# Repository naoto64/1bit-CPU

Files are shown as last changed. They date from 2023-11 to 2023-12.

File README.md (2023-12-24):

# 1bit-CPU
1bit CPU using 74HC series logic IC.

## Overview
This is a 1bit CPU KiCad file.
You can make a CPU using the 74HC series logic IC.

## Circuit Diagram
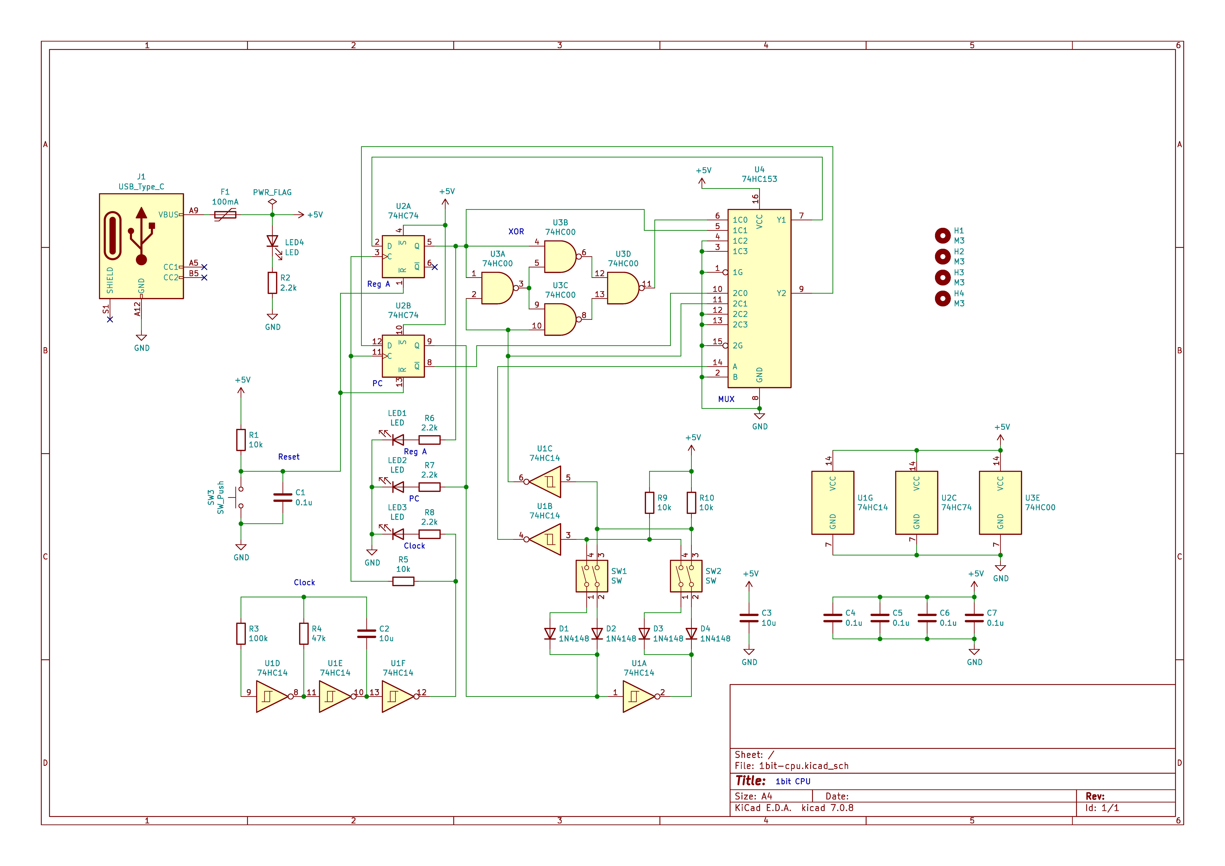
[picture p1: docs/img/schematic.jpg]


## Description
Left switch: Controls MUX to choose whether to update Reg A or PC  
Right switch: Controls second XOR operand or sets destination PC address

```
LR
00: MUX=0, RA=RA^0=RA,  PC=!PC
01: MUX=0, RA=RA^1=!RA, PC=!PC
10: MUX=1, RA=RA,       PC=0
11: MUX=1, RA=RA,       PC=1
```

In regular words:  
OFF, OFF will preserve the value of A and advance PC (0->1, 1->0)  
OFF, ON will invert the value of A (0->1, 1->0) and advance PC (0->1, 1->0)  
ON, OFF will preserve the value of A and set PC to 0  
ON, ON will preserve the value of A and set PC to 1  

```
01 23 | Function | Looped C equivalent | Description
----------------------------------------------------------------------------
00 00 | NOP, NOP | void; void;         | Do nothing
00 01 | NOP, INV | void; a=!a;         | Half frequency blink
00 10 | NOP, NOP | void; void;         | Do nothing
00 11 | NOP, HLT | void; while(1);     | Halt forever
01 00 | INV, NOP | a=!a; void;         | Half frequency blink
01 01 | INV, INV | a=!a; a=!a;         | Maximum frequency blink
01 10 | INV, NOP | a=!a; void;         | Half frequency blink
01 11 | INV, HLT | a=!a; while(1);     | Usually one state change, then halt
10 00 | HLT, NOP | while(1); void;     | Halt forever
10 01 | HLT, INV | while(1); a=!a;     | At most one state change, then halt
10 10 | HLT, NOP | while(1); void;     | Halt forever
10 11 | HLT, HLT | while(1); while(1); | Halt forever
11 00 | NOP, NOP | void; void;         | Do nothing
11 01 | NOP, INV | void; a=!a;         | Half frequency blink
11 10 | NOP, NOP | void; void;         | Do nothing
11 11 | NOP, HLT | void; while(1);     | Halt forever
```

## Video
1bit-CPU (https://www.youtube.com/watch?v=7_g6IDrb5PI)

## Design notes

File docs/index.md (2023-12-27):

# 1bit CPU 組み立てキット

## 概要
4個のロジックICを使用した1bit CPUの組み立てキットです。
超低性能なコンピュータのため、Lチカ、LED点灯、LED消灯のいずれかしかできません。
世界トップクラスの低性能コンピュータです。

電源はUSB Type-C端子です。ACアダプタ、ケーブルは付属しておりませんので別途ご用意ください。また、PowerDelivery等の給電には対応しておりませんのでご注意ください。

## 購入
この製品は以下のサイトから購入できます。  
[スイッチサイエンス - 1bit CPU 組み立てキット](https://www.switch-science.com/products/9376 "1bit CPU 組み立てキット")

#### お問い合わせフォーム
[製品に関するお問い合わせ](https://forms.gle/Fn5E3byABXJ8P5sbA)

## 使用方法
ROM書き込みはDIPスイッチを切り替えることで可能です。

DIPスイッチは上側がONです。プログラムで赤色LEDの点灯動作が変わります。赤色のリセットボタンを押すとリセットできます。

## スペック
<table>
  <thead>
    <tr>
      <th>項目</th>
      <th>スペック</th>
    </tr>
  </thead>
  <tbody>
    <tr>
        <td>汎用レジスタ</td>
        <td>1bit x 1</td>
    </tr>
    <tr>
        <td>アドレス空間</td>
        <td>2bit</td>
    </tr>
    <tr>
        <td>アドレスバス幅</td>
        <td>1bit</td>
    </tr>
    <tr>
        <td>ROM容量</td>
        <td>4bit</td>
    </tr>
    <tr>
        <td>命令セット</td>
        <td>ADD, JMP</td>
    </tr>
    <tr>
        <td>プログラムカウンタ</td>
        <td>1bit</td>
    </tr>
    <tr>
        <td>フラグレジスタ</td>
        <td>未実装</td>
    </tr>
    <tr>
        <td>算術演算</td>
        <td>1bitの加算（XOR）</td>
    </tr>
    <tr>
        <td>クロック周波数</td>
        <td>約1Hz</td>
    </tr>
    <tr>
        <td>IC総数</td>
        <td>4個</td>
    </tr>
  </tbody>
</table>

## 命令セット
<table>
  <thead>
    <tr>
      <th>命令</th>
      <th>機械語</th>
      <th>説明</th>
    </tr>
  </thead>
  <tbody>
    <tr>
        <td>ADD A, Im</td>
        <td>0</td>
        <td>AレジスタにIm（イミディエイトデータ）を加算する。</td>
    </tr>
    <tr>
        <td>JMP Im</td>
        <td>1</td>
        <td>Imで指定した先の番地へジャンプする。</td>
    </tr>
  </tbody>
</table>

## プログラム例
#### Aレジスタに1を加算し続けるプログラム（Lチカ）
ニモニック
```text:
ADD A, 1
JMP 0
```

DIPスイッチ
```text:
OFF　ON　ON　OFF
```

#### Aレジスタに1を加算するだけのプログラム
ニモニック
```text:
ADD A, 1
JMP 1
```

DIPスイッチ
```text:
OFF　ON　ON　ON
```

#### 何もしないプログラム
ニモニック
```text:
JMP 0
```

DIPスイッチ
```text:
ON　OFF　ON　OFF
```

## 回路図
回路図

## 実装図
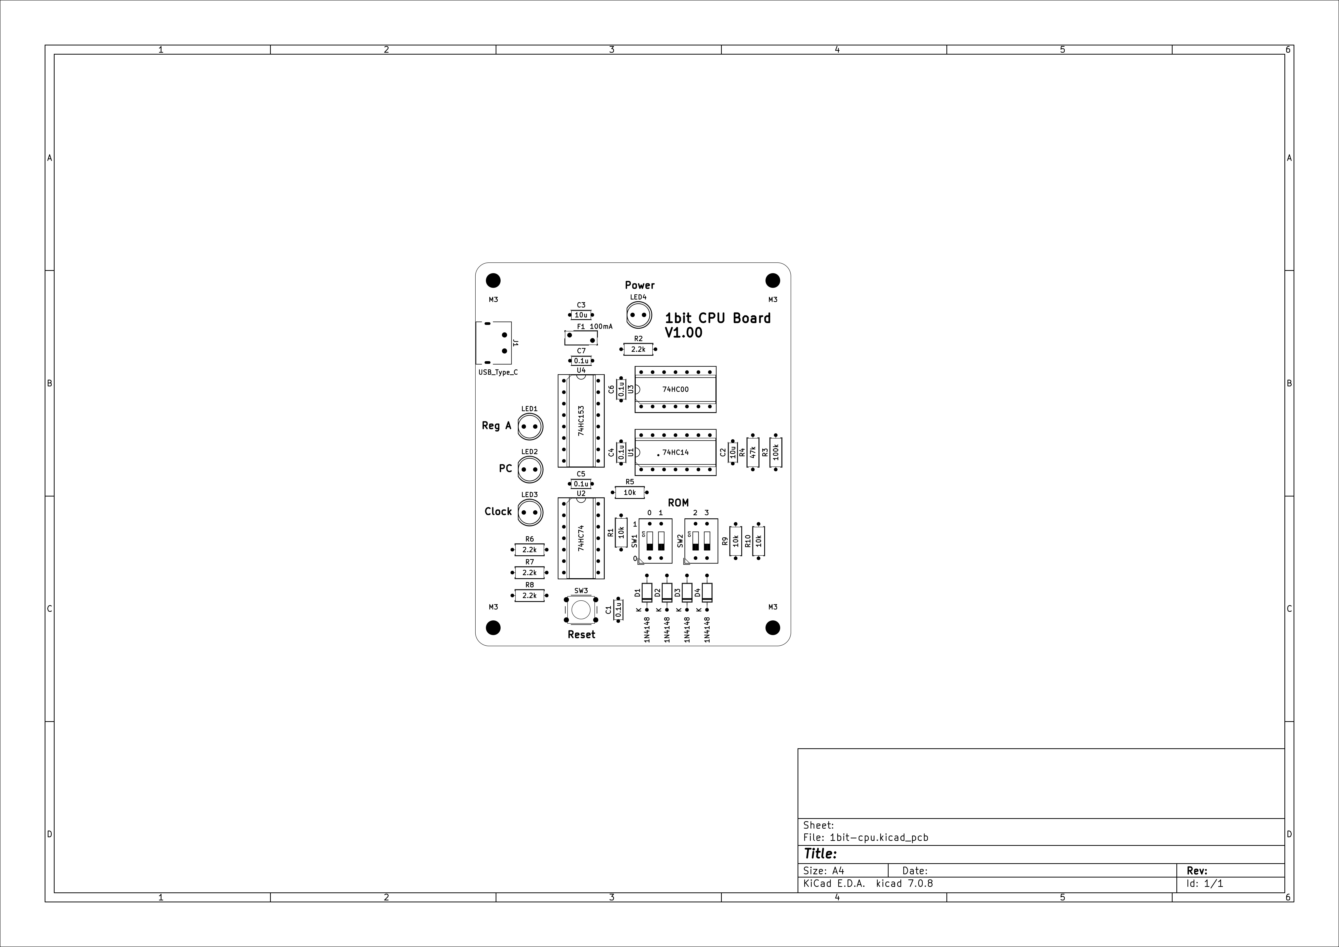
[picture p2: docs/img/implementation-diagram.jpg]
実装図


## 実装例
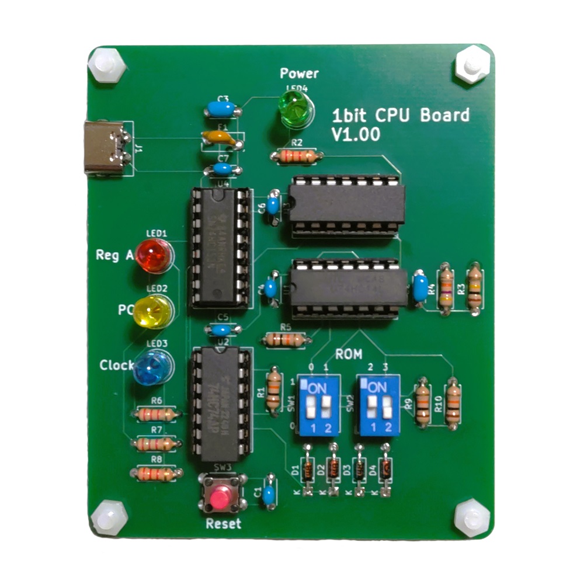
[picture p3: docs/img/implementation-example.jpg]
実装例


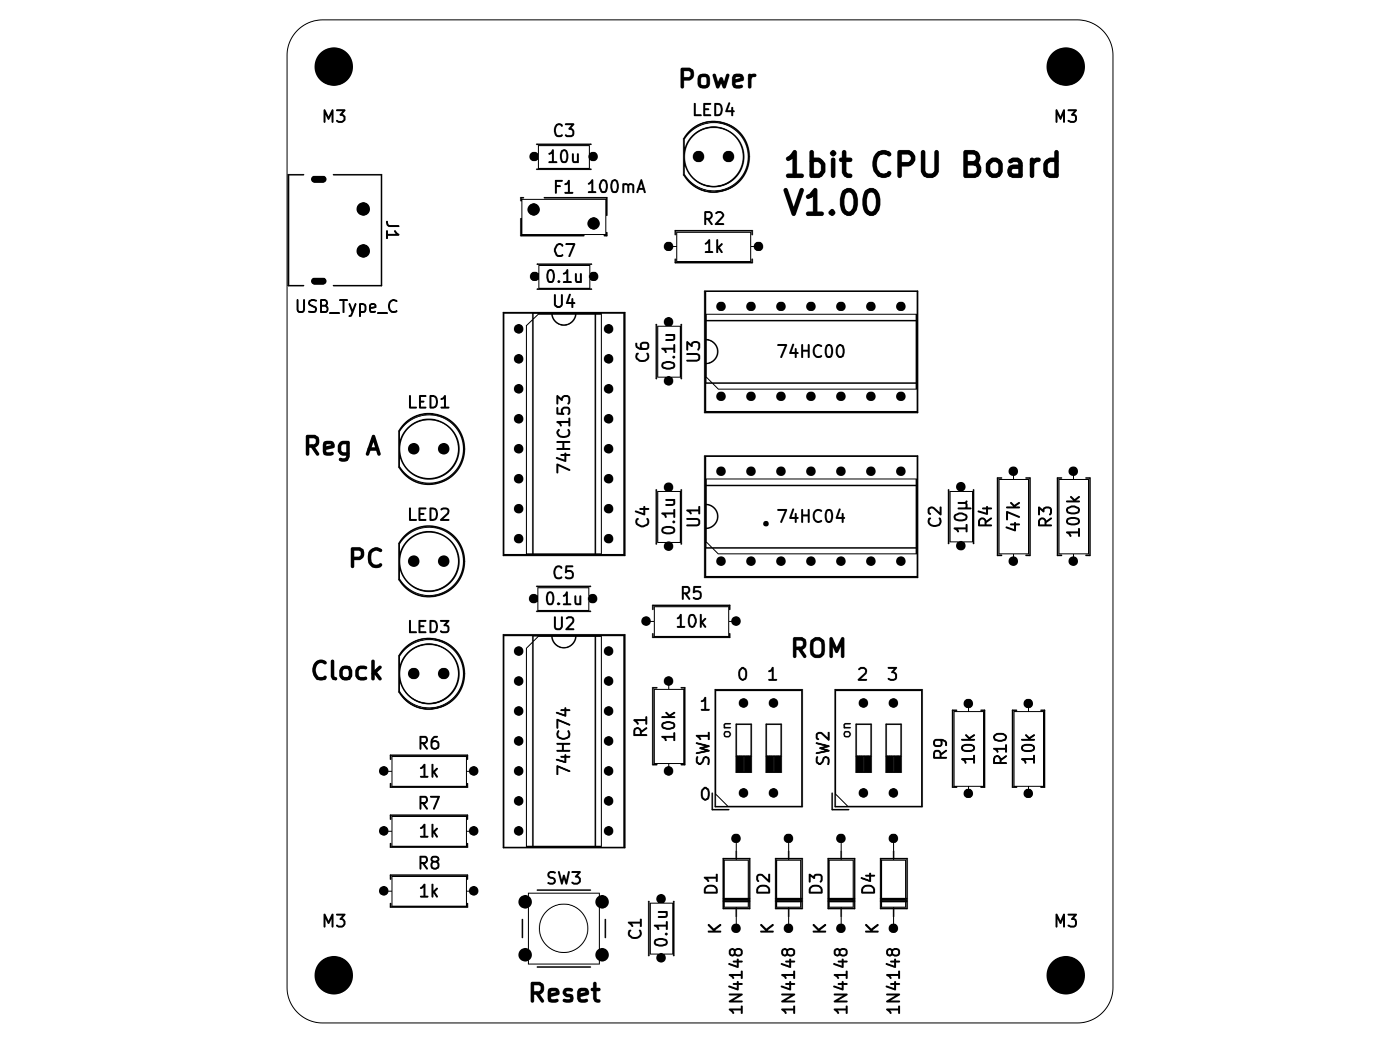
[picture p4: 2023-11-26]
1bit-cpu/実装図.png

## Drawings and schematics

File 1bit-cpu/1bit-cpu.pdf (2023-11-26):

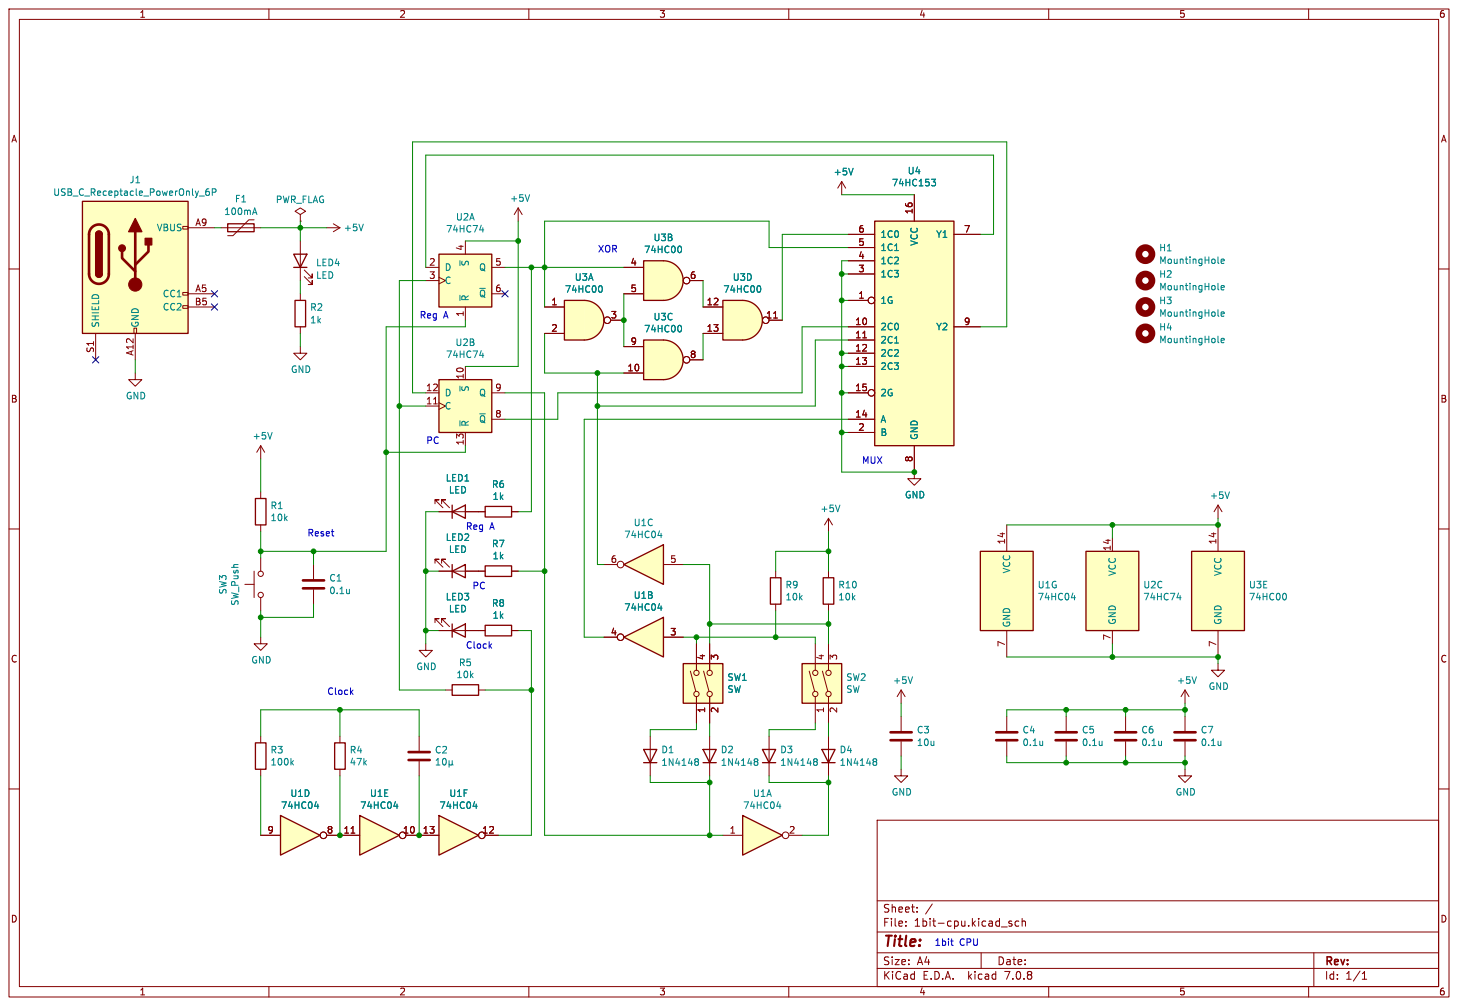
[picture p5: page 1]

74HC00 +5V H2 MountingHole H1 MountingHole H3 MountingHole H4 MountingHole

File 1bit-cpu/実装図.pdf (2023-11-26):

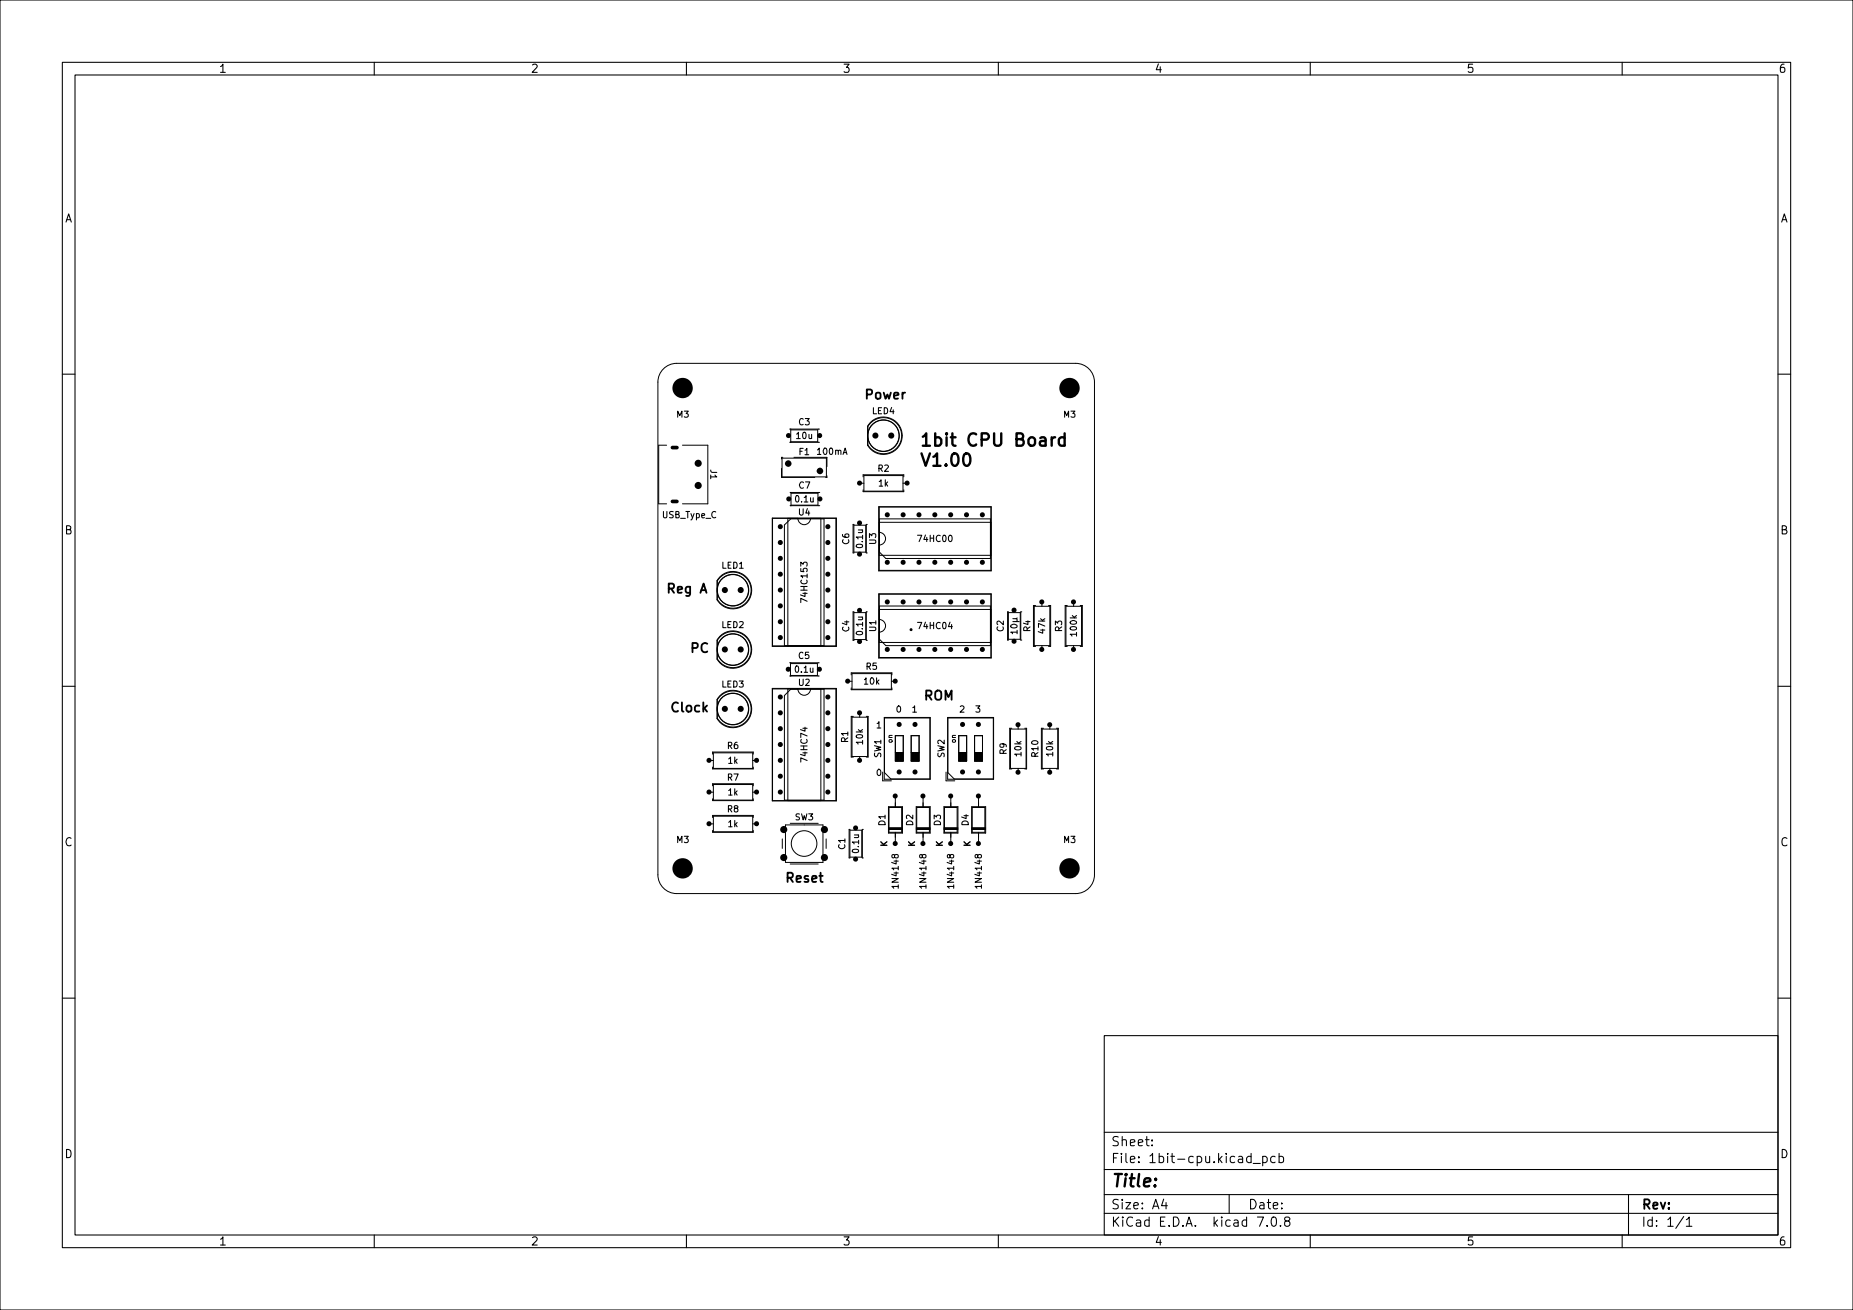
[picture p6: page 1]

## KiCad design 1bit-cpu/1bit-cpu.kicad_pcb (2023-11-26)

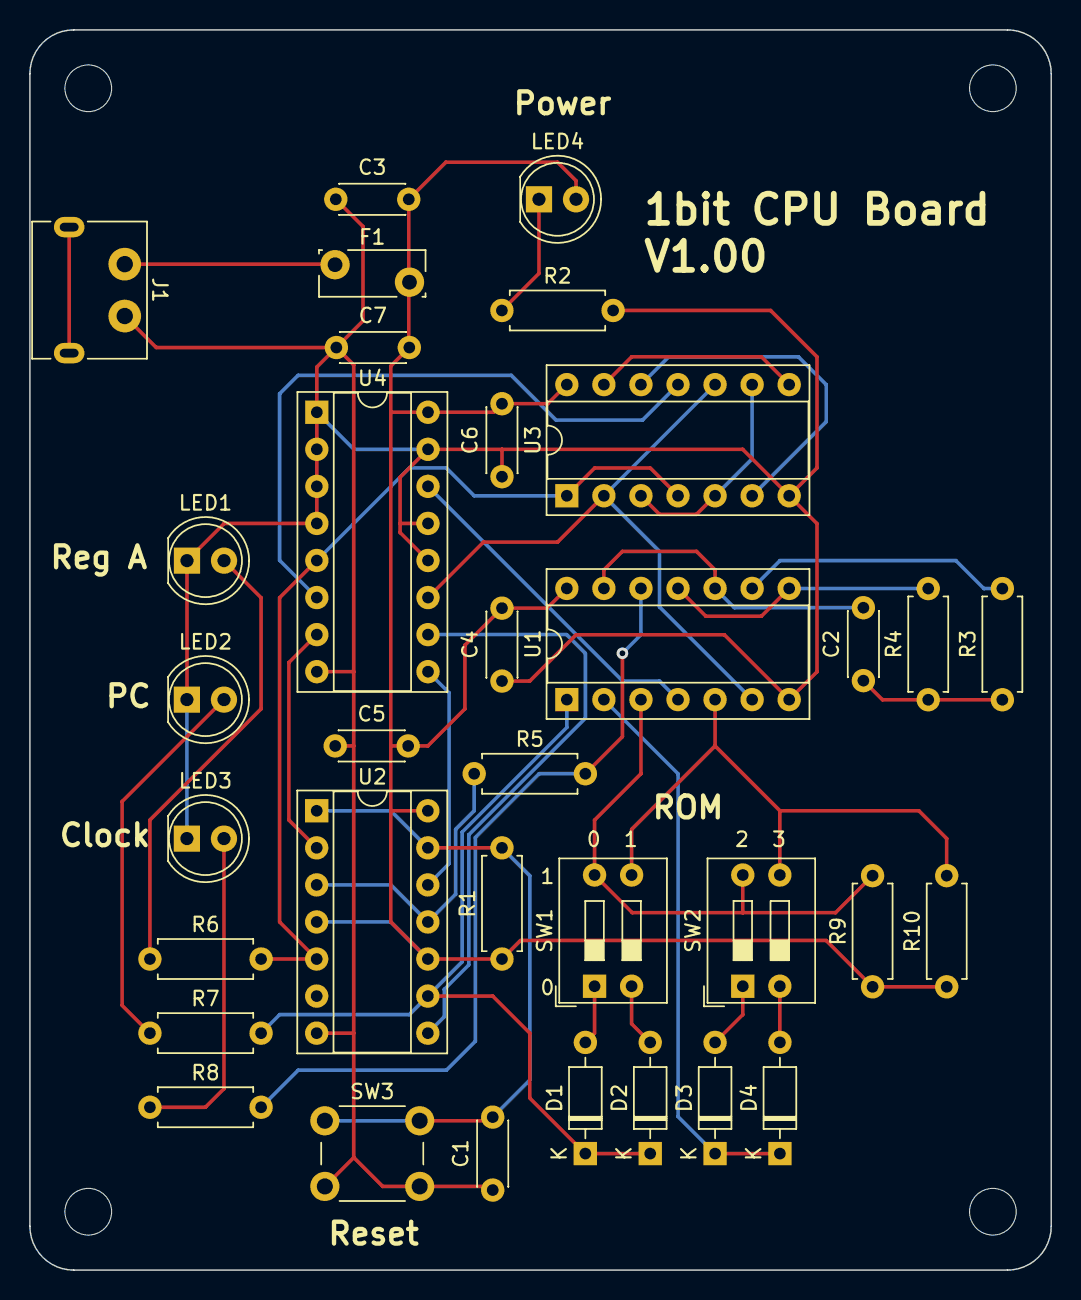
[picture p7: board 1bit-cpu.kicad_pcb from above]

Board: 2 copper layers, 70.0 x 85.0 mm, 38 parts (0 on the bottom side), 32 nets.

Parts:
C1, C4, C5, C6, C7: 0.1u; C_Disc_D4.3mm_W1.9mm_P5.00mm
C2: 10μ; C_Disc_D4.3mm_W1.9mm_P5.00mm
C3: 10u; C_Disc_D4.3mm_W1.9mm_P5.00mm
D1, D2, D3, D4: 1N4148; D_DO-35_SOD27_P7.62mm_Horizontal
F1: 100mA; Fuse_Bourns_MF-RG300
H1, H2, H3, H4: M3; MountingHole_3.2mm_M3
J1: USB_Type_C; USB_C_PowerOnly
LED1, LED2, LED3, LED4: LED; LED_D5.0mm
R1, R5, R9, R10: 10k; R_Axial_DIN0207_L6.3mm_D2.5mm_P7.62mm_Horizontal
R2, R6, R7, R8: 1k; R_Axial_DIN0207_L6.3mm_D2.5mm_P7.62mm_Horizontal
R3: 100k; R_Axial_DIN0207_L6.3mm_D2.5mm_P7.62mm_Horizontal
R4: 47k; R_Axial_DIN0207_L6.3mm_D2.5mm_P7.62mm_Horizontal
SW1, SW2: SW; SW_DIP_SPSTx02_Slide_9.78x7.26mm_W7.62mm_P2.54mm
SW3: SW_Push; SW_PUSH_6mm
U1: 74HC04; DIP-14_W7.62mm_Socket
U2: 74HC74; DIP-14_W7.62mm_Socket
U3: 74HC00; DIP-14_W7.62mm_Socket
U4: 74HC153; DIP-16_W7.62mm_Socket

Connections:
+5V: C3.2, C4.2, C5.2, C6.2, C7.2, F1.2, LED4.2 (A), R1.1, R9.1, R10.1, U1.14 (VCC), U2.4 (~S), U2.10 (~S), U2.14 (VCC), U3.14 (VCC), U4.16 (VCC)
GND: C1.1, C3.1, C4.1, C5.1, C6.1, C7.1, J1.A12 (GND), LED1.1 (K), LED2.1 (K), LED3.1 (K), R2.2, SW3.2, U1.7 (GND), U2.7 (GND), U3.7 (GND), U4.1 (1G), U4.2 (B), U4.3 (1C3), U4.4 (1C2), U4.8 (GND), U4.12 (2C2), U4.13 (2C3), U4.15 (2G)
unnamed: C2.1, R3.1, R4.1
unnamed: C2.2, U1.10, U1.13
unnamed: D1.2 (A), SW1.1
unnamed: D1.1 (K), D2.1 (K), R7.2, U1.1, U2.9 (Q)
unnamed: D2.2 (A), SW1.2
unnamed: D3.2 (A), SW2.1
unnamed: D3.1 (K), D4.1 (K), U1.2
unnamed: D4.2 (A), SW2.2
unnamed: F1.1, J1.A9 (VBUS)
unnamed: LED1.2 (A), R6.1
unnamed: LED2.2 (A), R7.1
unnamed: LED3.2 (A), R8.1
unnamed: LED4.1 (K), R2.1
unnamed: R3.2, U1.9
unnamed: R4.2, U1.8, U1.11
unnamed: R5.2, R8.2, U1.12
unnamed: R9.2, SW1.4, SW2.4, U1.3
unnamed: R10.2, SW1.3, SW2.3, U1.5
unnamed: R5.1, U2.3 (C), U2.11 (C)
unnamed: U2.2 (D), U4.7 (Y1)
unnamed: R6.2, U2.5 (Q), U3.1, U3.4, U4.5 (1C1)
unnamed: C1.2, R1.2, SW3.1, U2.1 (~R), U2.13 (~R)
unnamed: U2.12 (D), U4.9 (Y2)
unnamed: U2.8 (~Q), U4.10 (2C0)
unnamed: U3.3, U3.5, U3.9
unnamed: U3.6, U3.12
unnamed: U3.8, U3.13
unnamed: U3.11, U4.6 (1C0)
unnamed: U1.6, U3.2, U3.10, U4.11 (2C1)
unnamed: U1.4, U4.14 (A)

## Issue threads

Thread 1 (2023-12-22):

Add a truth table to explain switch positions

bmuessig, 2023-12-22:
I've had a quick look to reverse-engineer the circuit to understand what each of the switches does.

The below table explains the actions taken when the instruction is executed.
I think it would be helpful to add this to the documentation.

Left switch: Controls MUX to choose whether to update Reg A or PC
Right switch: Controls second XOR operand or sets destination PC address

```
LR
00: MUX=0, RA=RA^0=RA,  PC=!PC
01: MUX=0, RA=RA^1=!RA, PC=!PC
10: MUX=1, RA=RA,       PC=0
11: MUX=1, RA=RA,       PC=1
```

In regular words:
OFF, OFF will preserve the value of A and advance PC (0->1, 1->0)
OFF, ON will invert the value of A (0->1, 1->0) and advance PC (0->1, 1->0)
ON, OFF will preserve the value of A and set PC to 0
ON, ON will preserve the value of A and set PC to 1

bmuessig, 2023-12-22:
Here's a full table of all possible programs, while I was at it:

```
01 23 | Function | C equivalent        | Function
----------------------------------------------------------------------------
00 00 | NOP, NOP | void; void;         | Do nothing
00 01 | NOP, INV | void; a=!a;         | Half frequency blink
00 10 | NOP, NOP | void; void;         | Do nothing
00 11 | NOP, HLT | void; while(1);     | Halt forever
01 00 | INV, NOP | a=!a; void;         | Half frequency blink
01 01 | INV, INV | a=!a; a=!a;         | Double frequency blink
01 10 | INV, NOP | a=!a; void;         | Half frequency blink
01 11 | INV, HLT | a=!a; while(1);     | Usually one state change, then halt
10 00 | HLT, NOP | while(1); void;     | Halt forever
10 01 | HLT, INV | while(1); a=!a;     | At most one state change, then halt
10 10 | HLT, NOP | while(1); void;     | Halt forever
10 11 | HLT, HLT | while(1); while(1); | Halt forever
11 00 | NOP, NOP | void; void;         | Do nothing
11 01 | NOP, INV | void; a=!a;         | Half frequency blink
11 10 | NOP, NOP | void; void;         | Do nothing
11 11 | NOP, HLT | void; while(1);     | Halt forever
```

naoto64, 2023-12-24:
@bmuessig
Thank you very much.
Added a table of circuit operation and switch positions to the document.

bmuessig, 2023-12-27:
> @bmuessig Thank you very much. Added a table of circuit operation and switch positions to the document.

That's great! Have a good 2024.

Closed 2023-12-27.
